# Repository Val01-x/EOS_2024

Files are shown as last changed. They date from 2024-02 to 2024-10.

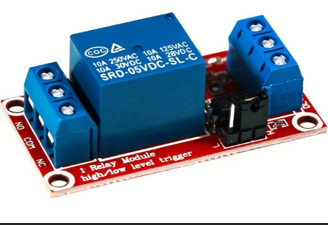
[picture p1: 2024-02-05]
Module sertissage/Composants/ModuleRelai.png

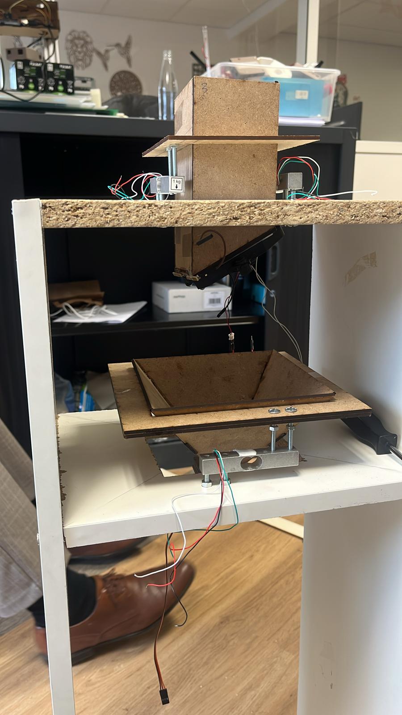
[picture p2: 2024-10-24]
Documentation/EOS complet/support + distribuer peser.jpeg

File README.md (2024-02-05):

   

Notre projet a pour vocation de promouvoir le développement des PME en leur proposant un outil adapté à leur besoin et à leurs moyens, leur permettant ainsi de mieux lutter contre la concurrence des grands groupes nationaux et internationaux. Pour ainsi dire, offrir aux petites entreprises une solution qui favorise leur développement et leur expansion sur le marché.
Une solution personnalisée et adaptée aux besoins de l’utilisateur permet ainsi d’accompagner l’entreprise dans une production plus automatisée et donc le développement de ces dernières.

## Accès
* [Codes](https://github.com/HugJax/EOS/tree/main/Codes)
* [Schéma électronique](https://github.com/HugJax/EOS/tree/main/Electronique)
* [Modèles 3D](https://github.com/HugJax/EOS/tree/main/Mod%C3%A8les%203D) ou sur [Thingiverse](https://www.thingiverse.com/thing:5220804)

## Open Source
Ce projet est open source, vous pouvez donc télécharger tous les fichiers pour pouvoir adapter la solution à vos besoins.

## Matériel nécessaire
Vous pouvez trouver les codes et modèles 3D (nous vous suggérons du Z-ABS) sur ce repository. Pour modifier les modèles 3D, ces derniers ont été réalisés grâce au logiciel fusion 360.  

Matériel nécessaire 

* Breadboard
* Arduino nano
* 2 micro-servo moteurs 9g MS18
* Convertisseur de tension (LED Converter) modèle 12V24-C
* cable USB mini-B
* Module reais SRD-05VDC-SL-C
* Fils femelle-femelle, mâle-mâle et mâle-femelle
* Planche de bois 30x60 cm
* Bobine de fil de nichrome de diamètre 0.2mm
* Deux breadboard
* Colle forte
* 3 boutons
* Un écran OLED 

Outils nécesaire 

* Pince (découpe cable)
* Découpeuse laser
* Arduino IDE
* Fer à souder

Pour la partie électronique, nous avons eu besoin de :
* [Cellule de charge](https://www.amazon.fr/s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)
* [HX711](https://www.amazon.fr/s?k=HX711&__mk_fr_FR=%C3%85M%C3%85%C5%BD%C3%95%C3%91&ref=nb_sb_noss_2)
* Breadboard
* Cables jumper
* Deux planches (les planches ne doivent pas se plier facilement, donc le mieux est de ne pas avoir un contreplaqué trop fin)
* Boulons plus longs + écrous correspondants

* [Ecran OLED](https://www.gotronic.fr/art-module-afficheur-oled-0-96-tf052-28511.htm)
* [Alimentation](https://www.amazon.fr/dp/B083LWHWKC)
* [Convertisseur 12V vers 5V](www.amazon.fr/Greluma-convertisseur-abaisseur-régulateur-dalimentation/dp/B08K37TS6F)
* Quatre boutons poussoirs
* Quatre résistances de 10kΩ et une de 5kΩ  

## Contribution
Si vous voulez contribuer au développement de ce projet, toute contribution d'une personne enthousiaste est la bienvenue. Pour cela, le projet EOS a maintenant un miroir sur GitHub, pour simplifier la vie de tout le monde ! Toutes les corrections de bogues, les nouvelles fonctionnalités, les nouveaux tutoriels, etc. doivent être soumis via le mécanisme de pull requests de GitHub.

Si vous n'êtes pas familier avec ce mécanisme, ne vous inquiétez pas, c'est très simple. Continuez à lire.

### Une introduction en bref
* Installer Git
* Enregistrez-vous sur GitHub. Créez votre fork du dépôt EOS https://github.com/HugJax/EOS (voir https://help.github.com/articles/fork-a-repo pour les détails)
* Choisissez une tâche pour vous-même. Il peut s'agir d'une correction de bogue ou d'un nouveau code
* Créez une branche de base pour votre travail
* Clonez votre fork sur votre ordinateur. Vous pouvez installer le hook pre-commit par défaut en renommant EOS/.git/hooks/pre-commit.sample en EOS/.git/hooks/pre-commit - cela vous évitera de commettre des erreurs d'espacement
* Créez une nouvelle branche (avec un nom significatif) à partir de la branche de base que vous avez choisie
* Modifiez ou ajoutez les codes/fichiers
* Lorsque vous avez terminé, push votre branche vers votre fork GitHub, puis créez une demande de transfert de votre branche vers la branche de base (voir https://help.github.com/articles/using-pull-requests pour plus de détails)

### Faire un bon pull request
En suivant ces directives, vous augmenterez les chances que votre demande soit acceptée :
* Avant de pousser votre PR vers le dépôt, assurez-vous qu'il se construit correctement sur votre système local
* Ajoutez suffisamment d'informations, comme un titre significatif, la raison pour laquelle vous avez fait la livraison et un lien vers la page du problème si vous en avez ouvert une pour ce PR
* Limitez votre PR à un seul problème. Avant de soumettre, assurez-vous que le diff ne contient pas de changements sans rapport. Si vous souhaitez couvrir plus d'un problème, soumettez vos modifications pour chacun d'entre eux dans des demandes de retrait distinctes
* Si vous avez ajouté une nouvelle fonctionnalité, vous devez mettre à jour/créer la documentation correspondante, ainsi qu'ajouter des tests pour cette fonctionnalité à la suite de tests
* Essayez de ne pas inclure de commits "oups" - ceux qui corrigent simplement une erreur dans le commit précédent. Si c'est le cas, avant de soumettre, intégrez ces corrections directement dans les commits auxquels elles appartiennent
* Veillez à ajouter un test pour la nouvelle fonctionnalité ou un test qui reproduit le bogue corrigé avec les données de test correspondantes. N'ajoutez pas d'images ou de vidéos supplémentaires, si certains des fichiers multimédias existants conviennent
* Veillez à ajouter un test de performance, si vous proposez une optimisation ou si le correctif peut affecter les performances d'une fonctionnalité majeure

Un grand merci à vous si cous nous aidez à développer ce projet en y contribuant.

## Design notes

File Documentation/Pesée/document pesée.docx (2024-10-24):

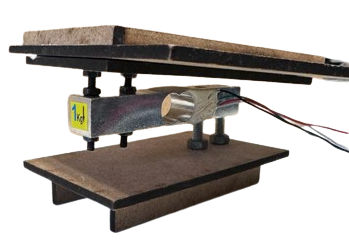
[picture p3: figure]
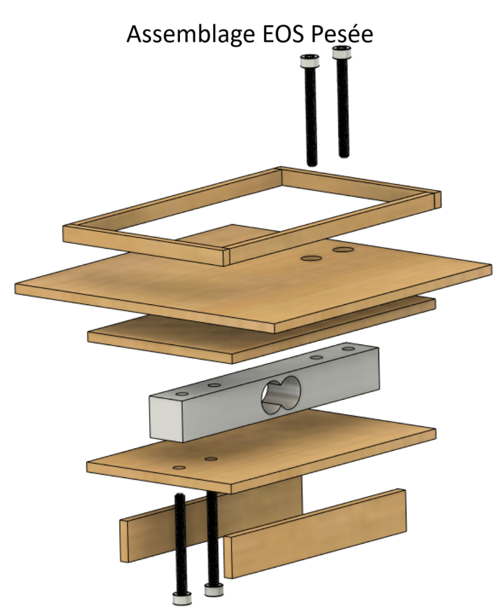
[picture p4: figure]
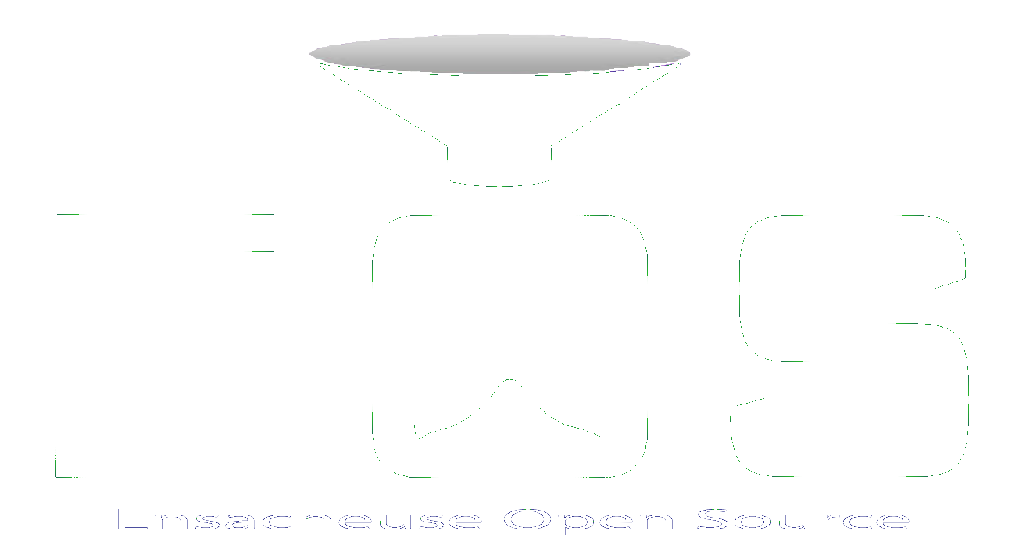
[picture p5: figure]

Capacité

- Force max : Dépendant de la cellule de charge

- Alimentation : Dépendant du module HX711

Module de Pesé

Ce dispositive permets de mesurer une force. Le plus souvent un Poid

Utilisation Possible

-Dosage et Ensachage Automatique

- Projets de Bricolage et d'Électronique

- Projets Éducatifs

- Contrôle Qualité

- Expérimentation en Laboratoire

Tableau de caractéristique

Liste module compatible

- EOS stocker

- EOS distribuer

Fil Entrée/sortie

- Rouge Entré

- Noir Entré

- Blanc Entré

- Vert Entré

Liste de composant

- Cellule de charge

- HX711

- Deux planches

- 4 Boulons longs

- 4écrous

Info de contacte

Clément Roux: clement.roux@edu.ece.fr

Romain Duffours: romain.duffours@edu.ece.fr

Hubert Biard de lary de latour: hubert.biarddelarydelatour@edu.ece.fr

Léo parent: leo.parent@edu.ece.fr

Valentin Droubay: valentin.droubay@edu.ece.fr

Alexandre DERIGENT: alexandre.derigent@edu.ece.fr

Projet ensacheuse opensource

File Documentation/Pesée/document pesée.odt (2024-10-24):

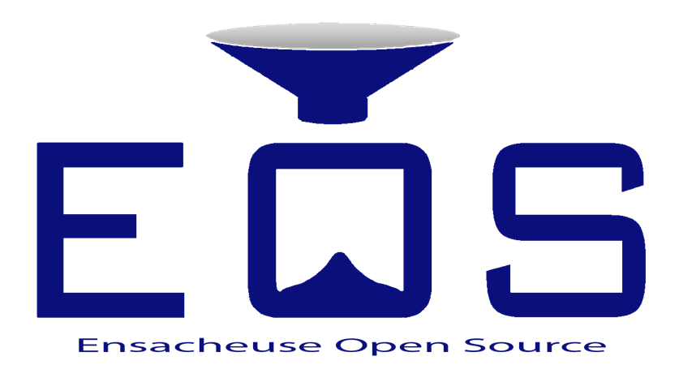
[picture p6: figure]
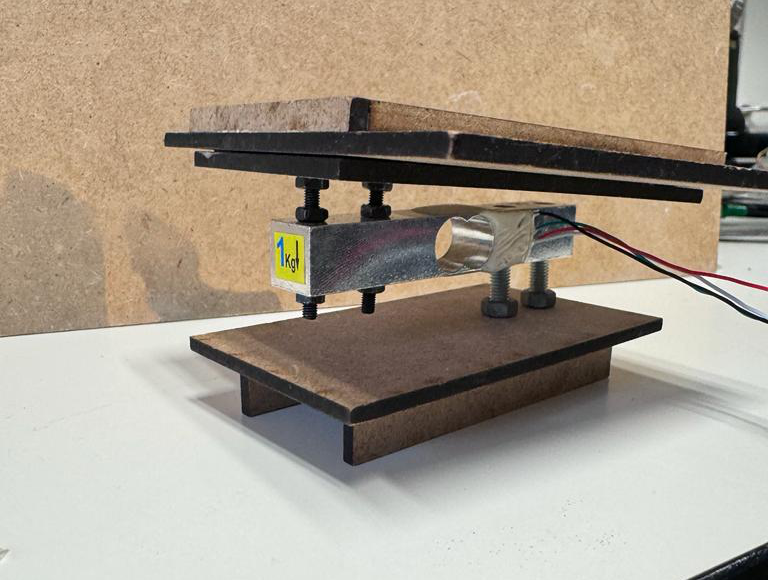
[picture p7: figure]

Utilisation Possible

- Dosage et Ensachage Automatique

- Projets de Bricolage et d'Électronique

- Agriculture Intelligente

- Pesage de Produits en Vrac

- Suivi du Poids Corporel

- Surveillance Environnementale

- Projets Éducatifs

- Contrôle Qualité

- Expérimentation en Laboratoire

Module de Pesé

Cette pesée est un module EOS conçu pour garantir une prise en compte précise du poids lors du processus d'ensachage. Sa précision, ajustable en fonction des besoins spécifiques, permet de s'assurer de l'exactitude des mesures. Composé d'une cellule de charge et d'un HX711 vert, sa facilité d'utilisation et de construction le rend particulièrement polyvalent. Pour la gestion de la pesée, l'utilisation d'une carte est indispensable, et nous recommandons l'utilisation d'une carte Arduino ou Raspberry Pi.


Liste module compatible

- EOS stocker

- EOS distribuer

Dimension

Liste de composant

- Cellule de charge

- HX711 vert

- Breadboard*

- Cable Jumper*

- Deux planches

- Boulons longs + écrous

Info de contacte

Clément Roux : clement.roux@edu.ece.fr

Romain Duffours : romain.duffours@edu.ece.fr

Hubert Biard de lary de latour: hubert.biarddelarydelatour@edu.ece.fr

Léo parent : leo.parent@edu.ece.fr

Valentin Droubay : valentin.droubay@edu.ece.fr

Alexandre DERIGENT : alexandre.derigent@edu.ece.fr

Projet ensacheuse opensource

Tableau de caractéristique

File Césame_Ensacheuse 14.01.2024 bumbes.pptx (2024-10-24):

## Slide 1

CESAMES
System Architecting Method
Ensacheuse Open-Source

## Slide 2

System Architecture

Insert illustration of the system

System name: Ensacheuse Open-Source
System Engineer 1: Derigent Alexandre
System Engineer 2: Roux clément

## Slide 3

CESAMES Method

Views

Description

CESAM - Grid

Expected
Properties

Needs

State

Static

Stakeh./Env
Use Cases

Dynamic

Operational Scenario

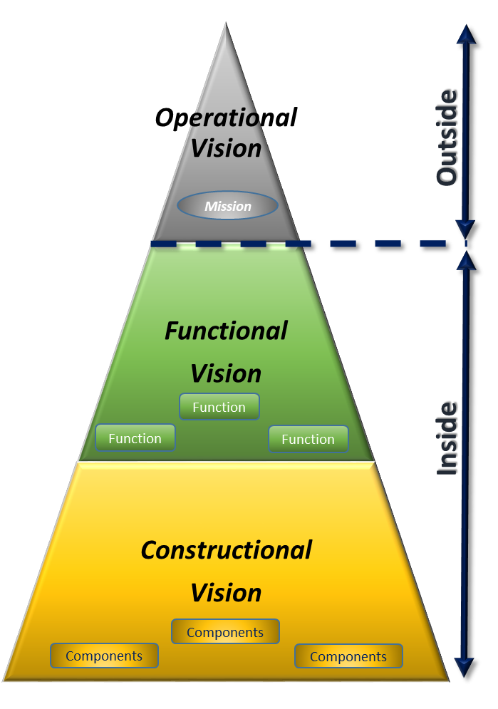
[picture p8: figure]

Mission

Life Cycle

Functional

Functional Requirements

Functional Mode

Functions

Functional Scenario

Viewpoints

Constructional

Constructional Requirements

Configuration

Constructional Scenario

Components

CESAMES introduction
Operational vision
Functional Vision
Constructional Vision

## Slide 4

Environment architecture

Stakeholders Analysis

hierarchy diagram + descriptions of each stakeholders

STAKEHOLDER

Utilisateurs finaux

Environnement
proche

Réseaux Wifi

Machine
électrique

Ordinateur

Développeur

Ingénieur x 6

Superviseur

Améliorateur

Élève de l‘ECE

Développeur inconnue

Petite entreprise

Vendeur

Sébastien MOITEL

Réseaux EDF

Github

Geoffroy LARDEUX

Opérateur

## Description

- Petite entreprise : une entreprise qui souhaite mettre dans un sachet une quantité précise de riz
- Vendeur : un vendeur qui vend des produits sur Internet, et qui souhaite mettre dans un sachet une certaine quantité de riz
- Opérateur : celui qui utilise la machine.
- Réseaux wifi : une technologie qui permet de transmettre et de communiquer des données
- Connection filaire : un type de connexion qui permet d'envoyer des données
- Téléphone : un appareil multifonction qui sert à envoyer et à recevoir des informations
- Ordinateur : un appareil multifonction qui sert à envoyer et à recevoir des informations
- Capteur : un appareil qui permet de transformer des informations physiques en données informatiques
- Servomoteur : un appareil qui convertit l'électricité en énergie rotationnelle
- Ingénieur : une équipe de six ingénieurs spécialisés dans divers domaines
- Sébastien MOITEL : le responsable du projet au sein de l'ECE
- Geoffry LARDEUX : le dépositaire du projet
- Élève de l'ECE : un futur ingénieur qui souhaite améliorer ou continuer le projet
- Développeur inconnu : quelqu'un qui a découvert le projet et qui souhaite y apporter des améliorations

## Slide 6

Environment architecture

Environment diagram + description of each relationship between the system and stakeholders

Stakeholders Analysis

Construit, surveillance,
avis

Utilisateurs finaux

Mise à jour, réparation

Dévellopeur

Ensacheuse Open source

Environnement
proche

Data, riz

Contrainte,
Conseil

Superviseur

Demande, data,
electricité

Feedback, amélioration
Version alternatives

Machine
électrique

Améliorateur

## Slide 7

Operational architecture

Introduce needs identified according to the CESAM Template

Besoin
EOS a besoin de mettre une certaine quantité(en gramme) de contenue dans un contenant
EOS a besoin d’être construisible par le grand public
EOS a besoin d’être améliorable par d‘autres collaborateurs
EOS a besoin de sceller un contenant
EOS a besoin d’être constitué de module indépendant capable de fonctionner hors d’EOS
EOS a besoin de ne pas utiliser pas de vis sans fin

Needs

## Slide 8

Operational architecture

Life Cycle Analysis

Introduce the Life Cycle Diagram + description of each phases

Système est réparer

Système est en panne

Développement

Actif

Réparation

Système validé par l‘ECE

Système en utilisation

Système à l‘arrêts

Système amélioré

Système est irréparable

Déploiement

Système et configuration choisi par un utilisateur final

Conception

Amélioration disponible, ou changement de configuration

recyclage

Stand-by

Amélioration

Systèmes prêts à l‘emploi

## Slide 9

Operational architecture

Introduce Use Cases (diagram or tabular approach)

Phase du cycle de vie | Cas d‘usage | Acteur
Active | Remplir un contenant spécifié avec une quantité précise de contenu en grammes à l'aide du système EOS. | Opérateur
Conception | Permettre à un utilisateur lambda de construire le système EOS sans nécessiter de compétences techniques avancées. | Utilisateur lambda
Amélioration | Permettre aux collaborateurs d'apporter des améliorations au système EOS de manière collaborative. | Elève de l’ECE, développeur inconnue

Uses Cases analysis

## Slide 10

Operational architecture

Introduce Use Cases (diagram or tabular approach)

Phase du cycle de vie | Cas d‘usage | Acteur
Active | Sceller hermétiquement un contenant à l'aide du système EOS. | EOS
Déploiement | Utiliser des modules indépendants d'EOS de manière autonome sans la nécessité de l'intégralité du système EOS. | Développeur, utilisateur lambda

Uses Cases analysis

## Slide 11

Operational architecture

Remplir un contenant spécifié avec une quantité précise de contenu en grammes à l'aide du système EOS.

Operational Scenario

Externe

Interne

Opérateur

EOS

Matière première(riz, sachet)

Rentre la quantité de riz par sachet

Rentre le nombre de sachet voulue

Si suffisamment de
matière première pour les
quantité = Faux

Indique quantité requise

Sachet remplie

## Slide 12

Operational architecture

Permettre à un utilisateur lambda de construire le système EOS sans nécessiter de compétences techniques avancées.

Operational Scenario

Externe

Interne

Utilisateur lambda

Sélectionne ses besoins parmi une liste

EOS

Fournit une liste de module

Choisie ses modules parmi la liste

Fournit le DIY des modules

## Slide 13

Operational architecture

Permettre à un utilisateur lambda de construire le système EOS sans nécessiter de compétences techniques avancées.

Operational Scenario

Externe

Interne

Dévellopeur

Apporte changement au github du projet

EOS

Report

Mise à jour correctement
implémenter

Passage en phase amélioration

Passage en phase Stand-by

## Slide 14

Operational architecture

Permettre à un utilisateur lambda de construire le système EOS sans nécessiter de compétences techniques avancées.

Operational Scenario

Interne

Eos module gestion

EOS module scellement

Requête de scellement sachet

Report, sachet sceller

Scellement sachet

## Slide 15

Operational architecture

Permettre à un utilisateur lambda de construire le système EOS sans nécessiter de compétences techniques avancées.

Operational Scenario

Externe

Interne

Utilisateur lambda

Sélectionne ses besoins parmi une liste

EOS

Fournit une liste de module

Choisie ses modules parmi la liste

Fournit le DIY des modules

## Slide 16

CESAMES Method

Views

Description

CESAM - Grid

Expected
Properties

Needs

State

Operational Context

Static

Stakeh./Env
Use Cases

Dynamic

Operational Scenario

Mission

Functional

Functional Requirements

Functional Mode

Functions

Functional Scenario

Viewpoints

Constructional

Constructional Requirements

Configuration

Constructional Scenario

Components

CESAMES introduction
Operational vision
Functional Vision
Constructional Vision

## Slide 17

Functional architecture

Functional Breakdown Analysis

Introduce functional breakdown structure + descriptions of each functions

Ensacheuse Open-source

Interagir avec l‘utilisateur

Gestion du contenue

Contrôler les informations

Gestion du contenant

Contrôler le system

Controller l‘énergie

Maintenance du système

Afficher les informations

Récupérer les requêtes utilisateur

Stocker le contenue

Peser le contenu

Vider le contenue dans le contenant

Collecter les informations

Placer
contenant

Ouvrir contenant

Remplir contenant

Gestion des modules

Acquérir l‘énergie

Informer de l‘état du projet

Proposer différente
configuration

Mettre à jour le système

Transmettre les informations

Gestion des versions

Distribuer
l‘énergie

Exploites les informations

Gestion des contenants

Sceller contenant

Gestion du contenue

Éjecter contenant

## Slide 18

Functional architecture

Functional Breakdown Analysis

Èlectrical machine

Computer

EOS

End User

Small compagny

seller

Opérator

Manage systeme

Manage
container

Gestion du content

Manage dat

Take information

Use informations

Transmit informations

Seal
Container

Gestion du contenant

Fiil
Container

End user

Small compagny

Seller

Operator

Gestion du contenu

Stock the content

Empty content into the container

Scale
content

Ditribute
Electrical power

Get electrical power

Mange électrical power

Interac with user

Show informations

Get User request

Machine
électrique

Ordinateur

nearby environnement

Réseaux Wifi

Réseaux EDF

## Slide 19

CESAMES Method

Views

Description

CESAM - Grid

Expected
Properties

Needs

State

Operational Context

Static

Stakeh./Env
Use Cases

Dynamic

Operational Scenario

Mission

Functional

Functional Requirements

Functional Mode

Functions

Functional Scenario

Viewpoints

Constructional

Constructional Requirements

Constructional Scenario

Configuration

Components

CESAMES introduction
Operational vision
Functional Vision
Constructional Vision

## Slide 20

Constructional requirement

Construction requirement analysis

Les requis de construction
EOS est capable de stocker 1 kg de contenue
EOS est construit à partir de matériel accessible au grand public
EOS est capable d’être mis à jour
EOS est disponible sous forme d’un DIY
EOS est facilement assemblable
EOS n’a pas de composant vis sans fin

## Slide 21

Constructional architecture

Constructional Breakdown Analysis

Introduce constructional breakdown structure + descriptions of each components

Ensacheuse Open-source

Interagir avec l‘utilisateur

Gestion du contenue

Bouteille

Contrôler les informations

Capteur, bibliothèque python

Câble, bibliothèque python

Raspberry ou Arduino nano

Gestion du contenant

?

Contrôler le system

Controller l‘énergie

Karyoosi

FangeHong, Raspberry ou Arduino nano

Maintenance du système

Bibliothèque python

Bibliothèque python

GitHub

Bibliothèque python

Bibliothèque python

Balance

?

Bibliothèque python

Electrovanne

Entonnoir

Bibliothèque python

Bibliothèque python

Résistance Nikrom

?

Bibliothèque python

Composant logiciel

Composant physique

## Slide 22

Constructionnal architecture

Constructional Interaction Analysis

Machine
électrique

Ordinateur

Utilisateurs finaux

Petite entreprise

Vendeur

Opérateur

Contrôler les informations

Capteur, bibliothèque python

Raspberry ou Arduino nano

Câble, bibliothèque python

Usb

Interagir
avec l‘utilisateur

Bibliothèque python

Bibliothèque python

Usb

I2c, bit

Contrôler le system

Bibliothèque python

Bibliothèque python

Bibliothèque python

GitHub

Maintenance du système

Bibliothèque python

Bibliothèque python

Bibliothèque python

bac

?

Résistance
Nikrom

?

?

Gestion du contenant

Gravité

Gestion du contenu

Bouteille

Électrovanne

Balance

Ouverture stockage riz

Entonnoir

I2c, bit

Utilisateurs finaux

Petite entreprise

Vendeur

Opérateur

Circuit électrique

FangeHong, Raspberry ou Arduino nano

Karyoosi

Controller l‘énergie

EOS

Usb

Prise
électrique

Environnement
proche

Réseaux Wifi

Réseaux EDF

Zone stockage sachet

Machine
électrique

Ordinateur

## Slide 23

Function to component correspondance

| composant
Fonction | Bibliothèque python | Bouteille | Balance | Electrovanne | Capteur | Câble | Raspberry ou Arduino nano | Entonnoir | Résistance Nikrom | GitHub | Karyoosi | FangeHong | ?
Afficher les informations | X
Récupérer les requêtes utilisateur | X
Stocker le contenue | | X
Peser le contenu | | | x
Vider le contenue dans le contenant | | | | x
Collecter les informations | X | | | | x
Transmettre les informations | X | | | | | X
Exploites les informations | | | | | | | X
Placer contenant | | | | | | | | | | | | | x
Ouvrir contenant | | | | | | | | | | | | | X
Remplir contenant | | | | | | | | X
Sceller contenant | | | | | | | | | X
Éjecter contenant | | | | | | | | | | | | | X
Gestion des modules | X
Gestion des versions | | | | | | | | | | X
Gestion des contenants | X
Gestion du contenue | X
Acquérir l‘énergie | | | | | | | | | | | X
Distribuer l'énergie | | | | | | | | | | | | x

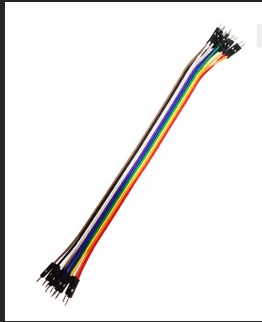
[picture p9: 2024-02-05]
Module sertissage/Composants/Fils .png

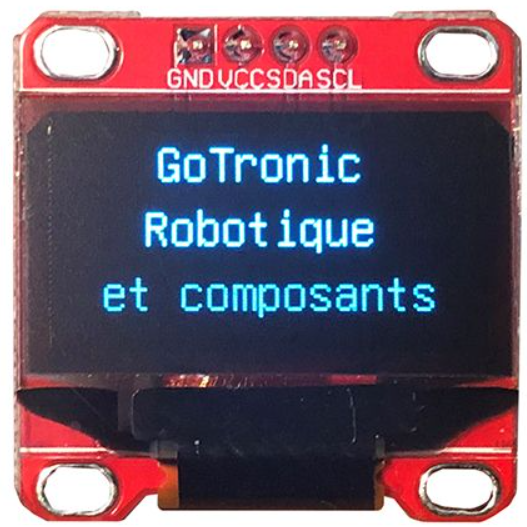
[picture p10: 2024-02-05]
Module sertissage/Composants/Ecran OLED.png

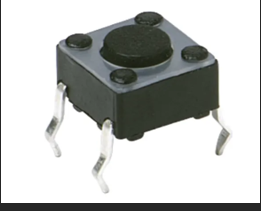
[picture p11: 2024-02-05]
Module sertissage/Composants/Boutons Poussoirs.png

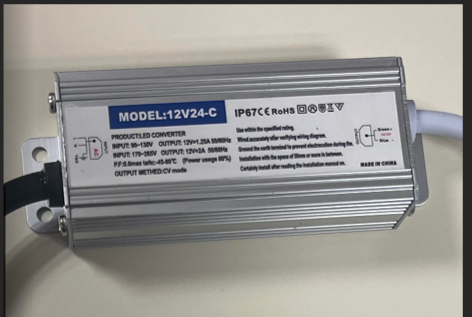
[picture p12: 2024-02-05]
Module sertissage/Composants/ConvertisseurDeTension.png

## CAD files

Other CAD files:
Documentation/Pesée/Modele 3d cellule de charge.blend
Documentation/Pesée/Modéle 3d vis type 1.blend
Documentation/Pesée/Modéle 3d vis type 2.blend
Documentation/Pesée/Modéle 3d écrou type 1.blend

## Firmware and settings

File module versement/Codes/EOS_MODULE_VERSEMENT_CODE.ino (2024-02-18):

//
//    FILE: EOS_MODULE_VERSEMENT_CODE
// PURPOSE: Versement de 100g
// Utilisation: Connecter la piéce sur un ordinateur et appuyer sur entré
//              dans le serial monitor pour demander 100g 

//---------------------------------------Begin Initialisation scale
#include "HX711.h"
HX711 scale1;
HX711 scale2;

//scale 3
uint8_t dataPin1 = 3;
uint8_t clockPin1 = 2;

//scale 4
uint8_t dataPin2 = 8;
uint8_t clockPin2 = 7;

float weight_before_opening;
float weight_after_opening;
//---------------------------------------End Initialisation scale

//---------------------------------------Begin Initialisation servo
#include <Servo.h>

Servo myservo;

int Open_servo = 90;
int Close_servo = 0;

//---------------------------------------End Initialisation scale

//---------------------------------------Begin Recever
int portion=100;
//---------------------------------------End Recever

//---------------------------------------Begin Initialisation

void setup() {
  //---------------------------------------Begin Setup Recever
  Serial.begin(9600);
  //---------------------------------------Begin Setup Recever
  
  //---------------------------------------Begin Setup servo
  myservo.attach(9);
  myservo.write(Close_servo);
  delay(5000);
  myservo.detach();
  //---------------------------------------End Setup servo

  //---------------------------------------Begin Setup scale
  scale1.begin(dataPin1, clockPin1);
  scale2.begin(dataPin2, clockPin2);

  scale1.set_offset(4294538449);
  scale1.set_scale(1029.004028);

  scale2.set_offset(4294924964);
  scale2.set_scale(1090.996459);
  //---------------------------------------End Setup servo
}


void loop() {
  //---------------------------------------Begin Loop receiver/ Waiting Sequence
  while (Serial.available()) Serial.read();
  Serial.println("do you want a portion?");
  while (Serial.available() == 0);
  //---------------------------------------End Loop receiver/ Waiting Sequence

  //---------------------------------------Begin Dosing sequence
  weight_before_opening = scale1.get_units() + scale2.get_units();
  weight_after_opening = scale1.get_units() + scale2.get_units();
  Serial.print("Before: ");
  Serial.println(scale1.get_units() + scale2.get_units());
  myservo.attach(9);
  myservo.write(Open_servo);
  while (weight_after_opening > weight_before_opening - portion + 50) {
    weight_after_opening = scale1.get_units() + scale2.get_units();
  }
  myservo.write(60);
  while (weight_after_opening > weight_before_opening - portion + 7) {
    weight_after_opening = scale1.get_units() + scale2.get_units();
  }
  myservo.write(Close_servo);
  delay(1000);
  myservo.detach();
  weight_after_opening = scale1.get_units() + scale2.get_units();
  Serial.print("delta: ");
  Serial.println(weight_before_opening - weight_after_opening);
  //---------------------------------------End Dosing sequence
}


// -- END OF FILE --

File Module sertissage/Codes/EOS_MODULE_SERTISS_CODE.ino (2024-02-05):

//LIBRAIRIES

#include "Servo.h"
#include <Wire.h>
#include <Adafruit_GFX.h>
#include <Adafruit_SSD1306.h>


//OLED DISPLAY SIZE

#define SCREEN_WIDTH 128 
#define SCREEN_HEIGHT 64 


// Declaration for an SSD1306 display connected to I2C (SDA, SCL pins)
Adafruit_SSD1306 display(SCREEN_WIDTH, SCREEN_HEIGHT, &Wire, -1);


//RELAY PIN
const int digPin = 2;


//INITIAL CLOSING DURATION

int duration = 30;


//SERVOS PIN

Servo servod; 
Servo servog; 


void setup() {
 	
 	Serial.begin(9600);
 	Serial.println(F("Initialize System"));
 	

  //PIN MODE

 	pinMode(digPin, OUTPUT);
  pinMode(3, INPUT);
  pinMode(4, INPUT);
  pinMode(5, INPUT);

  
  //WE OPEN THE REALY - HEATING WIRE

  digitalWrite(digPin, HIGH);


  //WE OPEN THE HATCH
  servod.attach(7);
  servog.attach(8);
  servod.write(80); 
  servog.write(90); 
  
  delay(1000);

  servod.detach(); 
  servog.detach(); 


  //WE INITIALIZE THE OLED DISPLAY

  if(!display.begin(SSD1306_SWITCHCAPVCC, 0x3C)) { // Address 0x3D for 128x64
    Serial.println(F("SSD1306 allocation failed"));
    for(;;);
  }
  delay(2000);
  display.clearDisplay();
  display.clearDisplay();
  display.setTextSize(4);
  display.setTextColor(WHITE);
  display.setCursor(0, 10);
  // Display static text
  display.println(duration);
  display.display();
  
}



void loop() {

  
  //WE READ THE STATE OF THE BUTTONS

  byte buttonStateSignal = digitalRead(4);
  byte buttonStateMinus = digitalRead(12);
  byte buttonStatePlus = digitalRead(11);

   
  //IF THE MINUS BUTTON IS PRESSED WE DECREASE THE DURATION
  //IF THE PLUS BUTTON IS PRESSED WE INCREASE THE DURATION
  //STEP = 1 SEC

  if (buttonStateMinus == LOW) {
    duration -= 1;
    display.clearDisplay();
    display.setTextSize(4);
    display.setTextColor(WHITE);
    display.setCursor(0, 10);
    // Display static text
    display.println(duration);
    display.display();
  }
  if (buttonStatePlus == LOW) {
    duration += 1;
    display.clearDisplay();
    display.setTextSize(4);
    display.setTextColor(WHITE);
    display.setCursor(0, 10);
    // Display static text
    display.println(duration);
    display.display();
  }
  

  //IF THE START BUTTON IS PRESSED WE CLOSE THE HATCH AND START SEALING THE BAG FOR THE ENTERED DURATION

  if (buttonStateSignal == LOW) {
      servod.attach(7);
      servog.attach(8);
      servod.write(170); 
      servog.write(0); 
      delay(1000);
      servod.detach(); 
      servog.detach(); 
      delay(duration*1000-2000);
      servod.attach(7);
      servog.attach(8);
      servod.write(80); 
      servog.write(90); 
      delay(1000);
      servod.detach(); 
      servog.detach(); 
  }
  
  delay(100);
  
}

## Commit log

2022-01-24 Première version de l'interface
    Création de la gestion du prototype avec l'utilisation de boutons et d'un écran LCD 1602.
    Version réalisée avant tests
2022-01-24 Première version de l'interface
2022-01-26 connexion avec la raspberry
2022-01-27 ajout du code + circuits électroniques
    [branchements fritzing.fzz]
2022-01-27 ajout des modèles 3D
    [base_vis.f3d, base_vis.stl, gouttiere .f3d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]
2024-02-05 Create Laser
2024-02-05 remove 3D
    [base_vis.f3d, base_vis.stl, gouttiere .f3d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]
2024-02-05 remove elect 2/3
    [branchements fritzing.fzz]
2024-02-05 refonte des composants + ReadMe
